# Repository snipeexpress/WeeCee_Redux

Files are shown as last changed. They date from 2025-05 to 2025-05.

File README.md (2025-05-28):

<!-- markdownlint-disable MD031 -->

# WeeCee Redux

**WeeCee Redux** is a hardware clone of Rasteri’s **WeeCee v0.3**, enhanced with a variety of improvements for modern usability, better component choices, and more robust design.

## Key Improvements

1. **HIDman Integration**  
   
   Replaced the legacy PS/2 port with [HIDman](https://github.com/Rasteri/HIDman), enabling support for modern USB HID devices via USB-to-PS/2 translation.

2. **Improved Audio Circuitry**  
   
   Refined the CS4237B circuitry for enhanced signal filtering and improved ground plane separation for cleaner audio performance.

3. **USB-C Power + On/Off Controller**  
   
   Replaced the micro-USB power input with USB-C. Integrated a **MAX16054** on/off controller for reliable power switching.

4. **On-Board PC Speaker**  
   
   Added a miniature PC speaker directly on the board. Can be disabled via jumper if not needed.

5. **Cost-Optimized Connectors**  
   
   Swapped out the MicroSD and audio output connectors for more affordable variants — the same ones used on Eivind Bøhler’s [TinyLlama](https://github.com/eivindbohler/TinyLlama).

6. **Enhanced Front Panel**  
   
   - Added a power button header for direct connection  
   - Added a reset button  
   - Added a power LED to indicate system status

7. **SD Card Activity Indicator**  
   
   Included circuitry and a front-panel LED to show real-time SD card activity.

8. **RTC Battery Support**  
   
   Added support for a **CR1220** coin cell battery to maintain Real-Time Clock settings.

## Enclosure Notes

This revision still fits the original enclosure used in Rasteri’s WeeCee v0.3. However, due to the added ports and indicators, **updated front and rear panels are required** for proper alignment.

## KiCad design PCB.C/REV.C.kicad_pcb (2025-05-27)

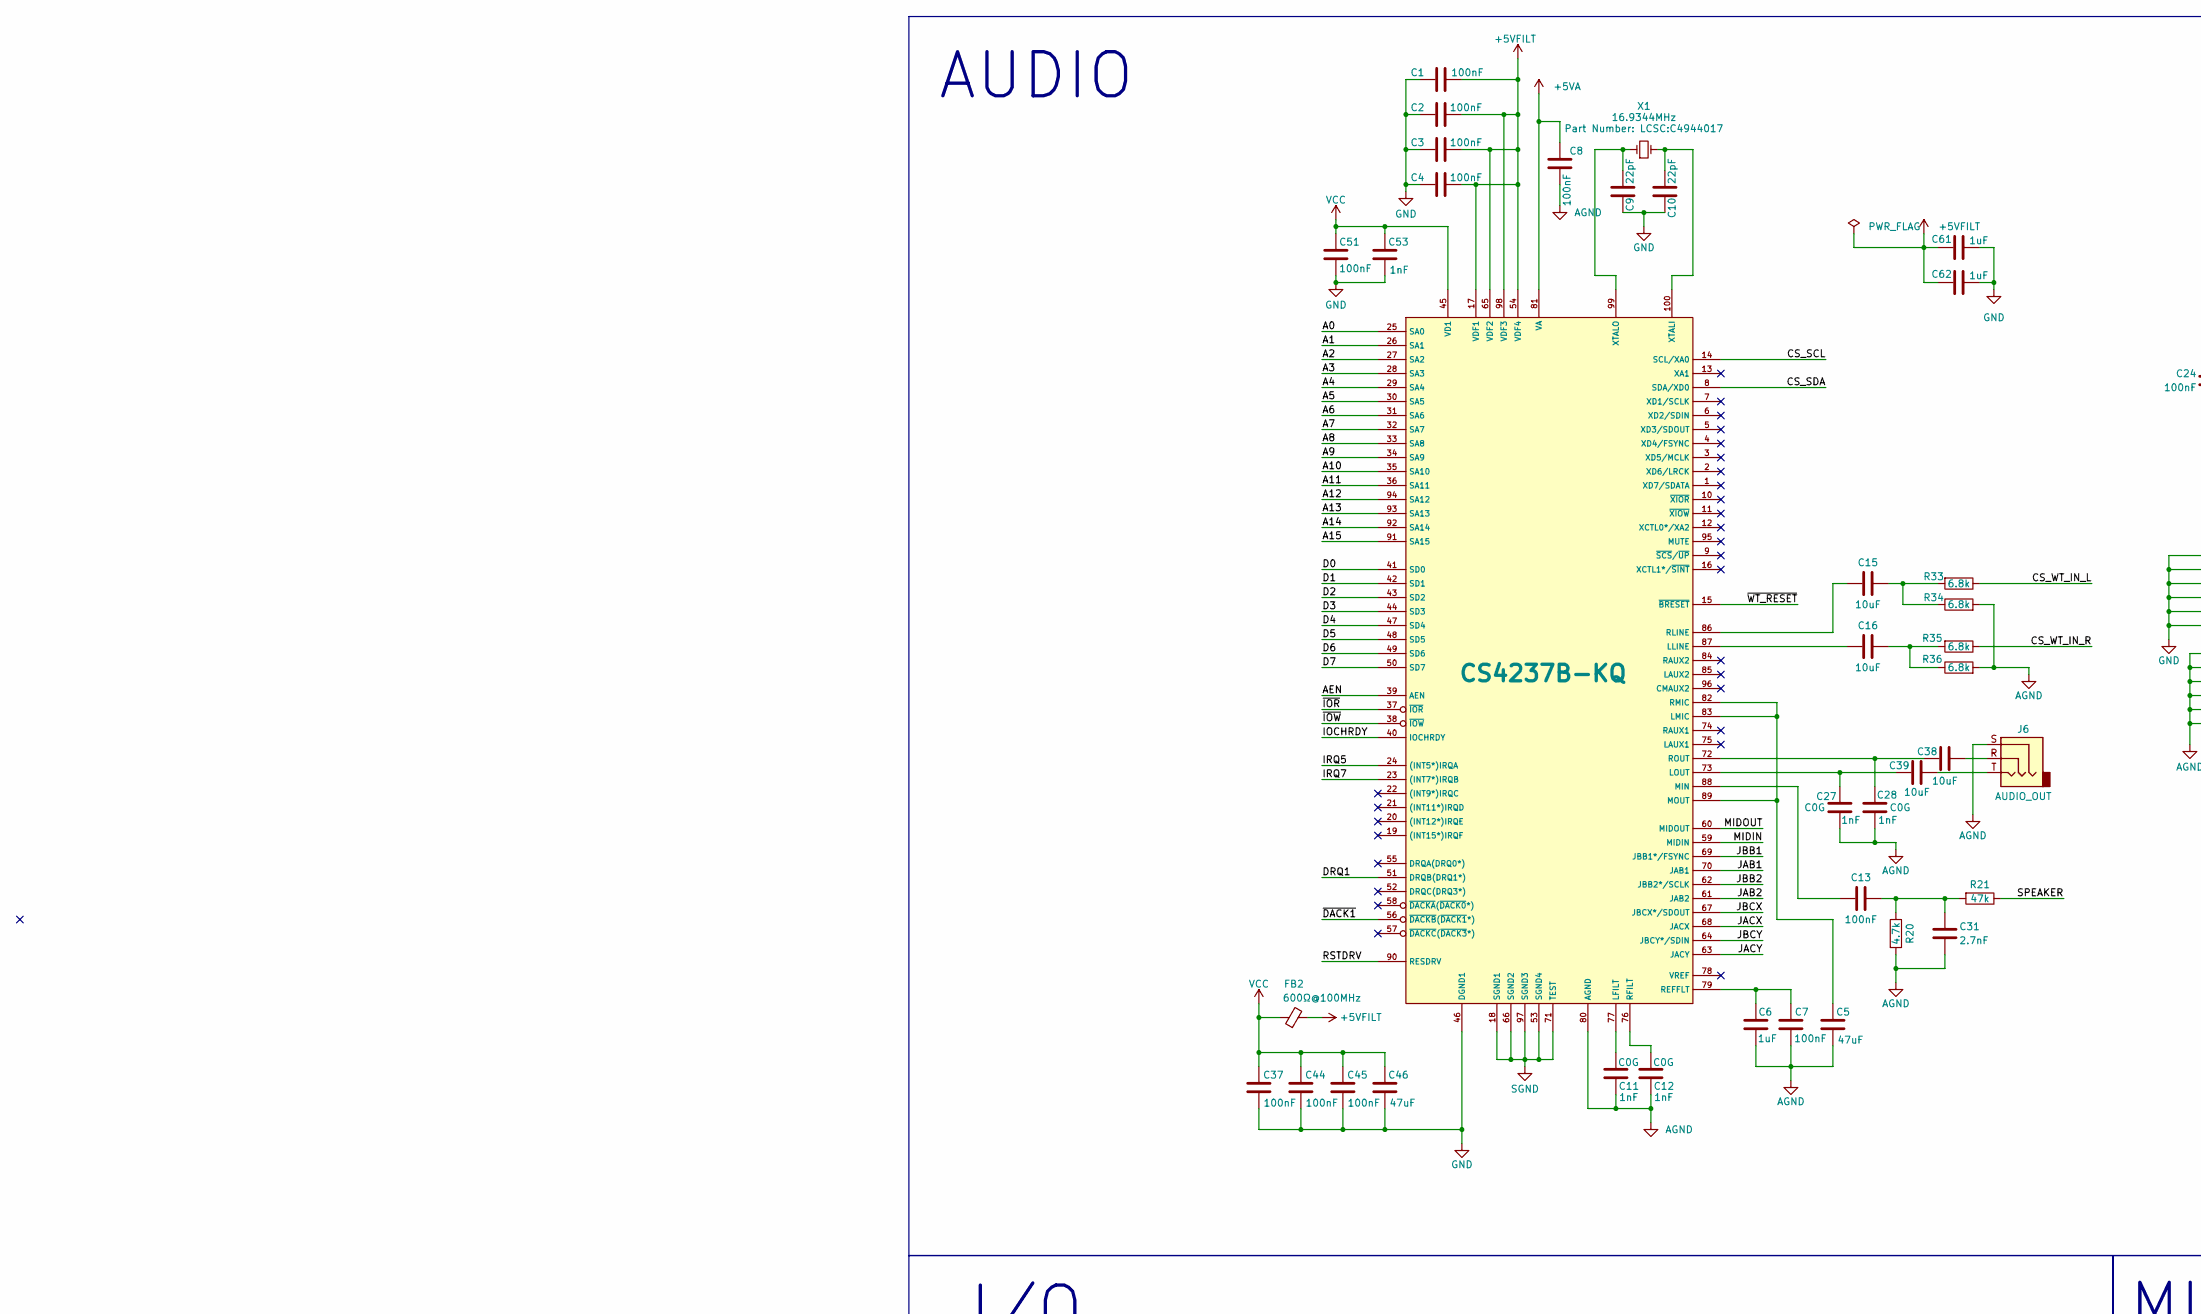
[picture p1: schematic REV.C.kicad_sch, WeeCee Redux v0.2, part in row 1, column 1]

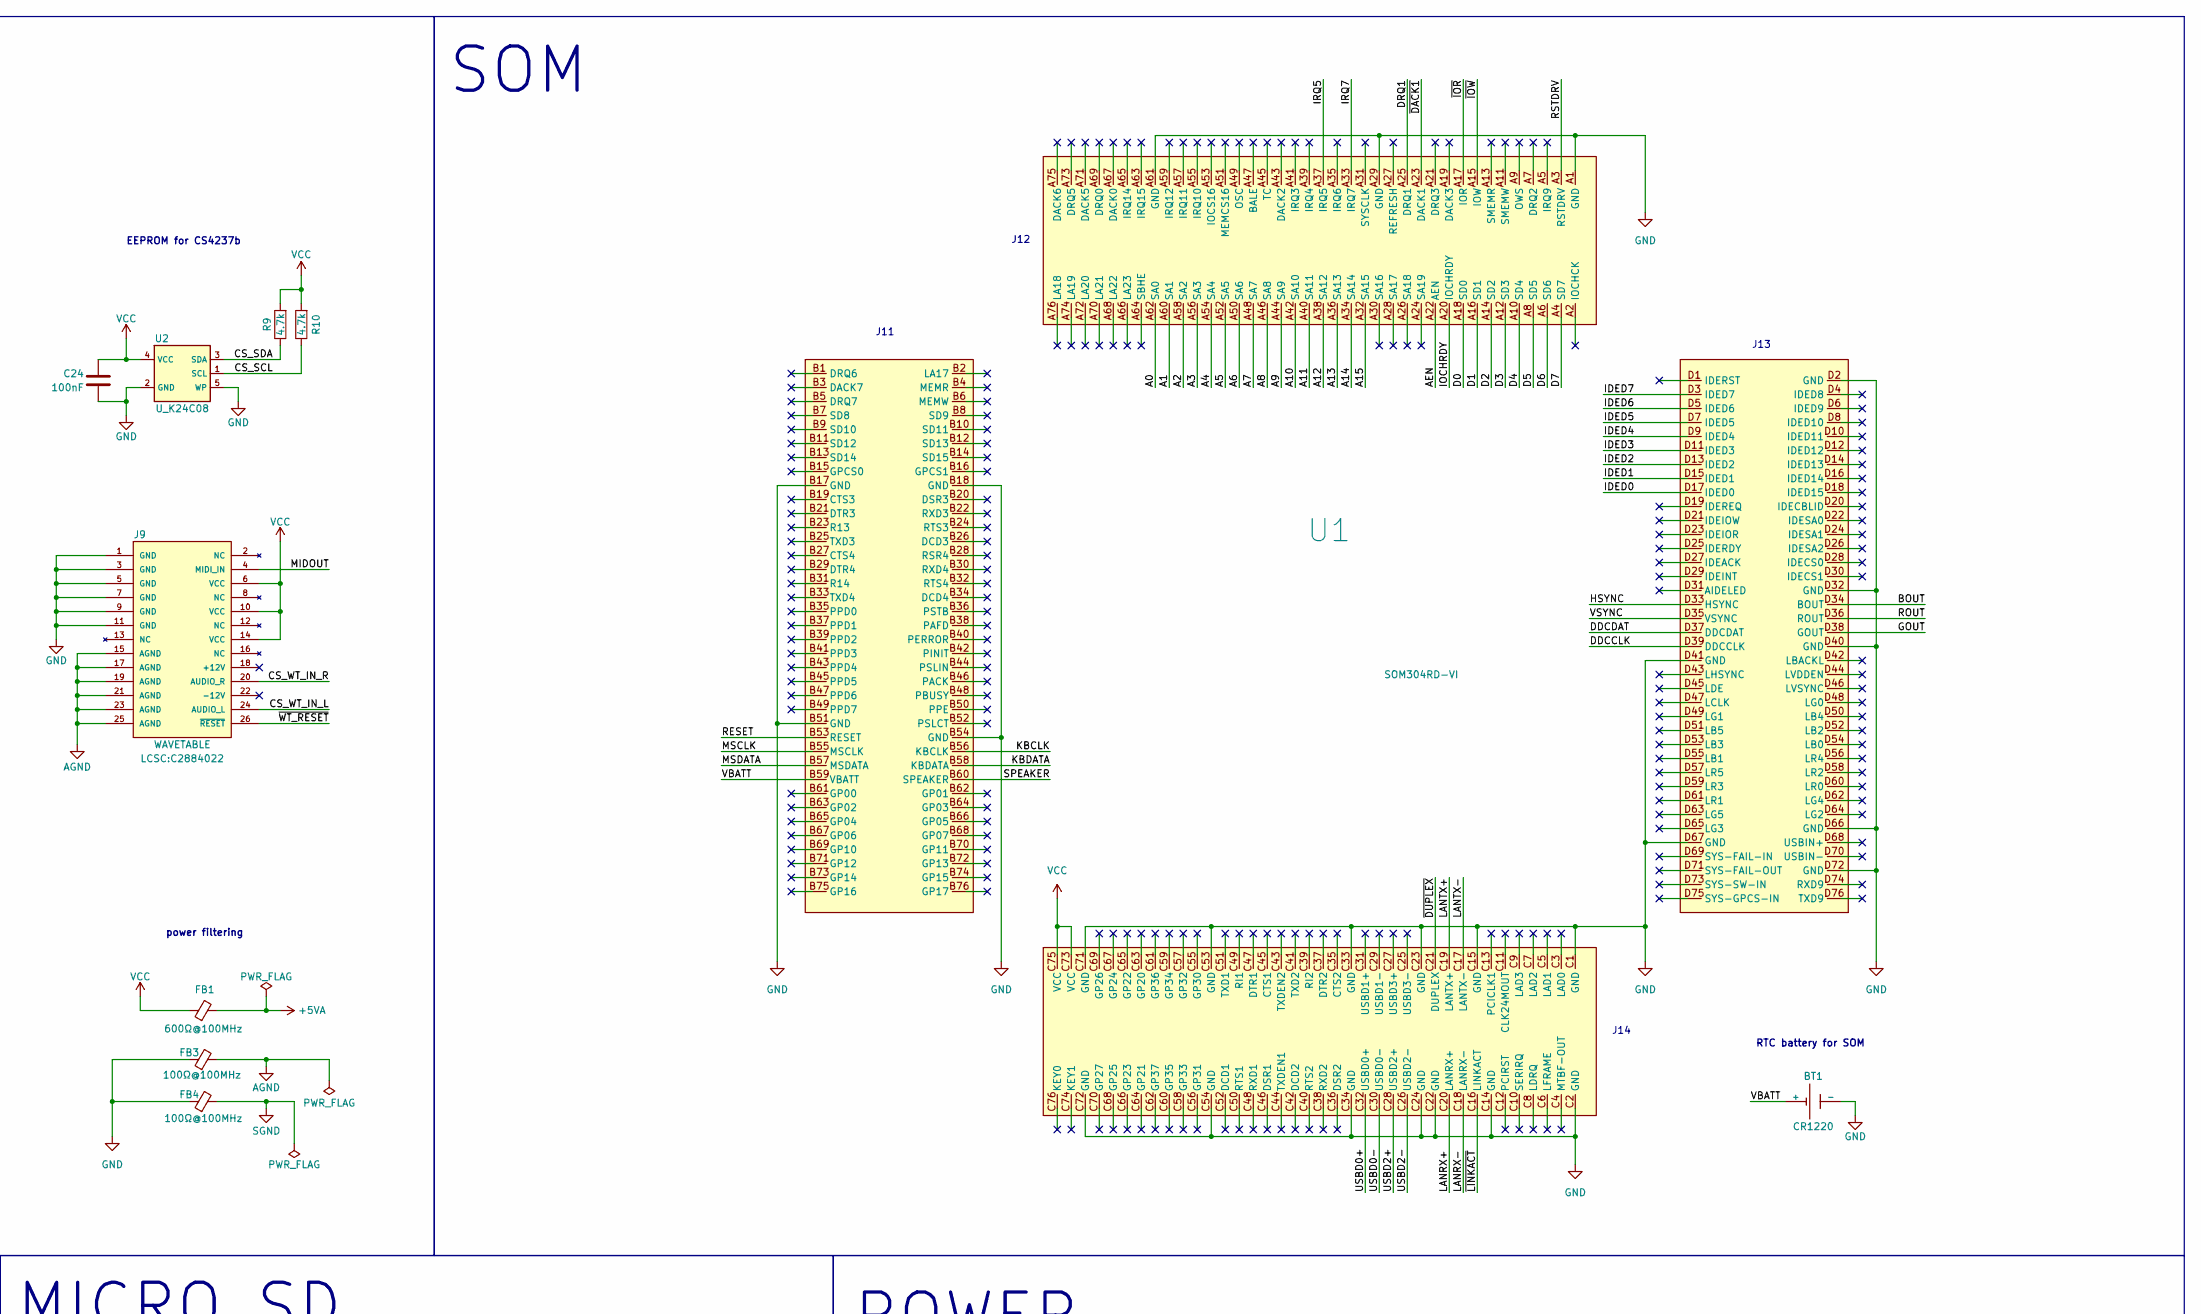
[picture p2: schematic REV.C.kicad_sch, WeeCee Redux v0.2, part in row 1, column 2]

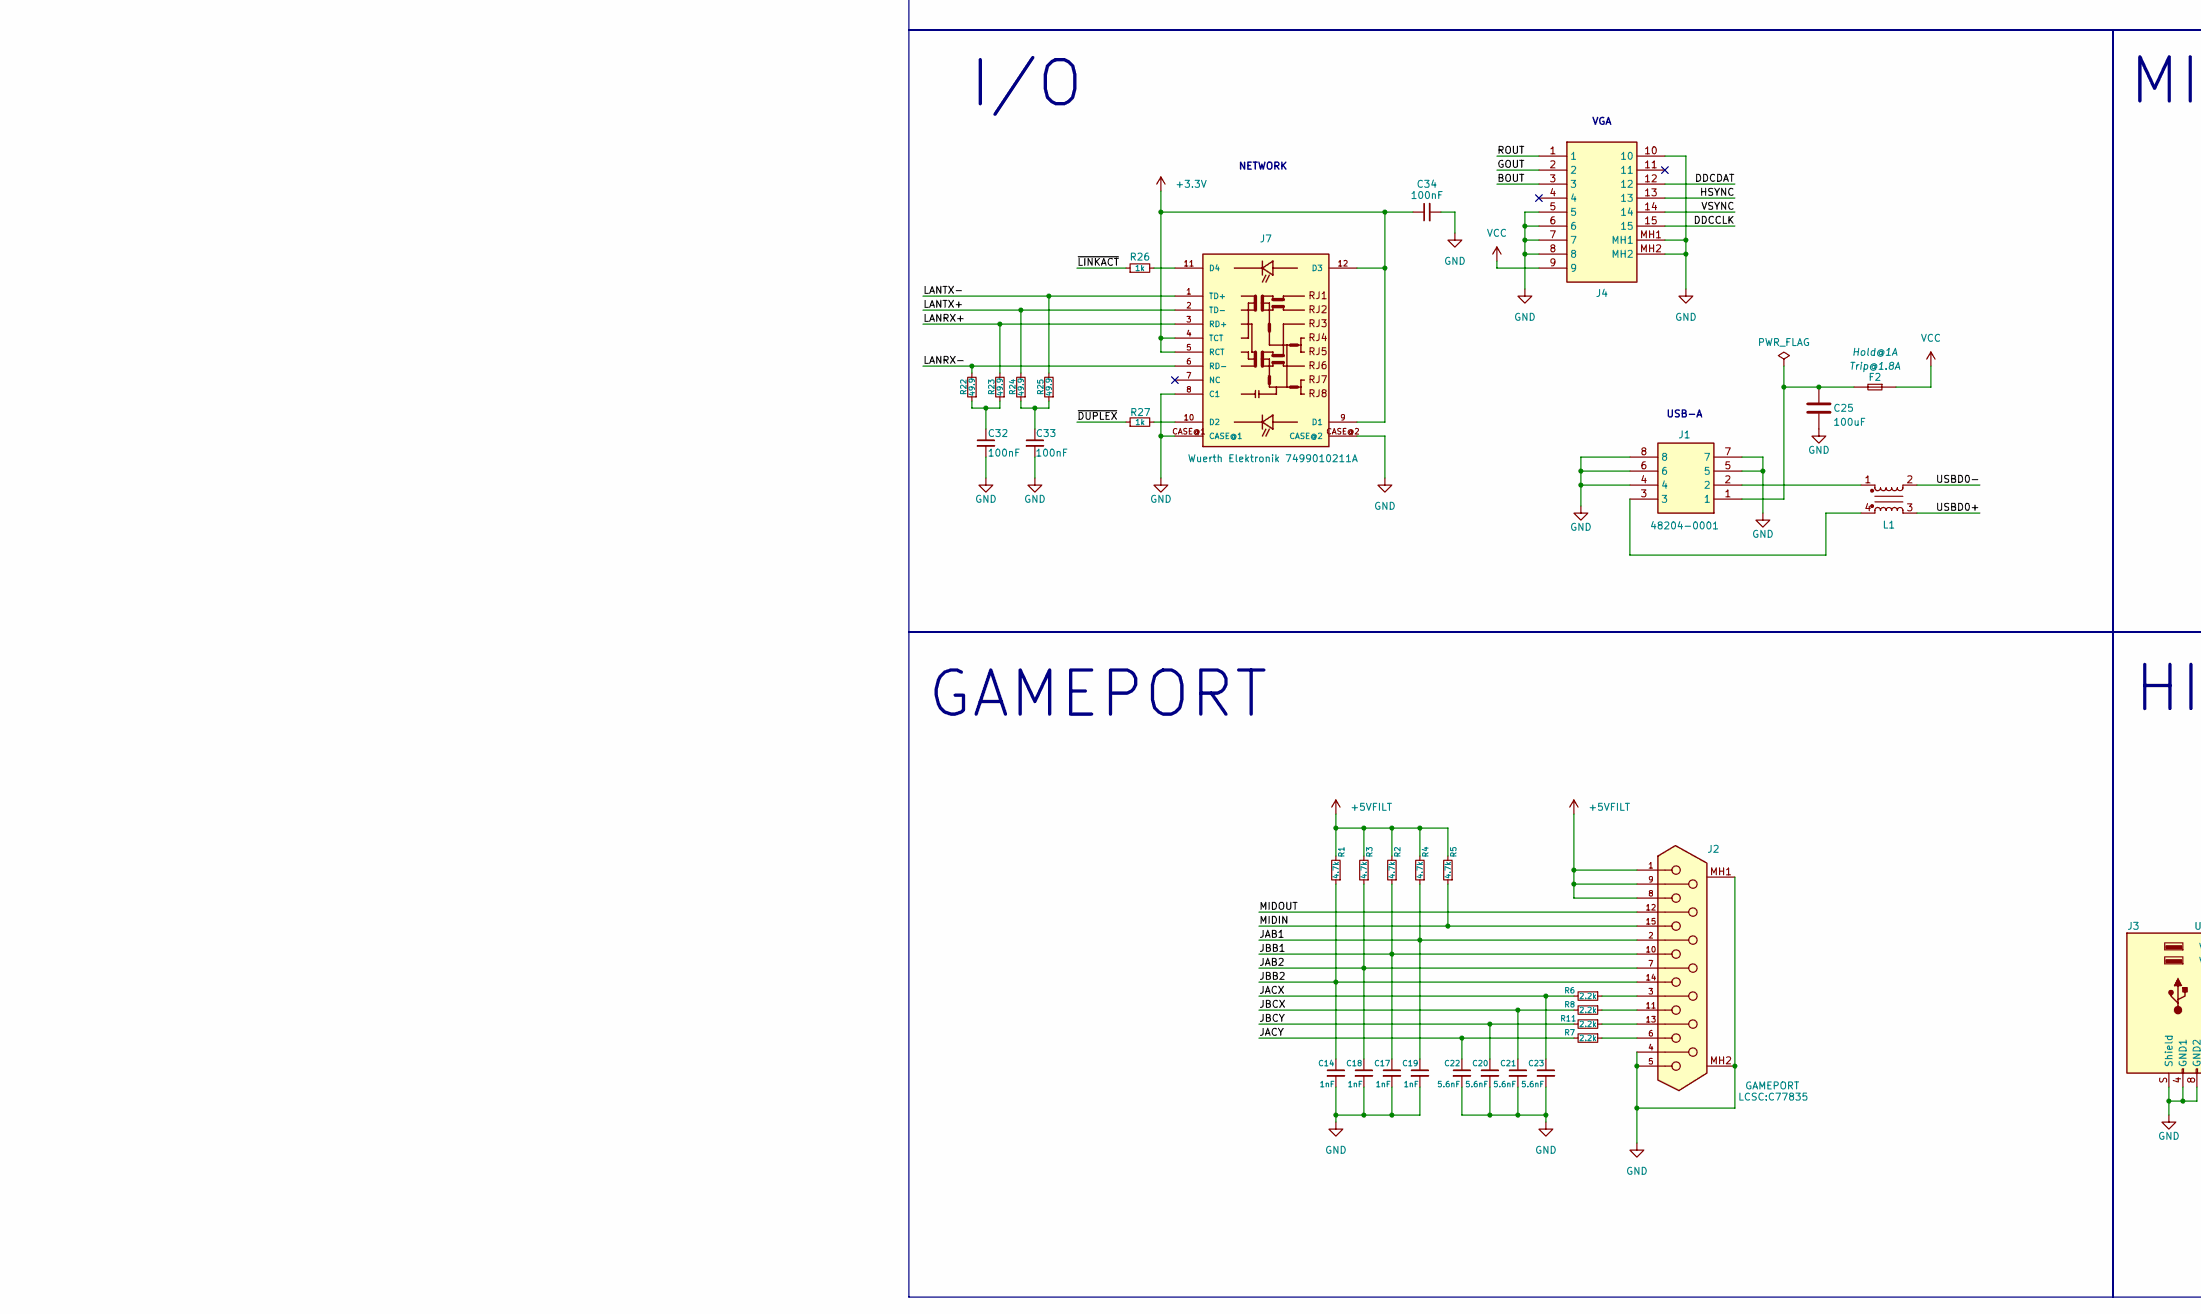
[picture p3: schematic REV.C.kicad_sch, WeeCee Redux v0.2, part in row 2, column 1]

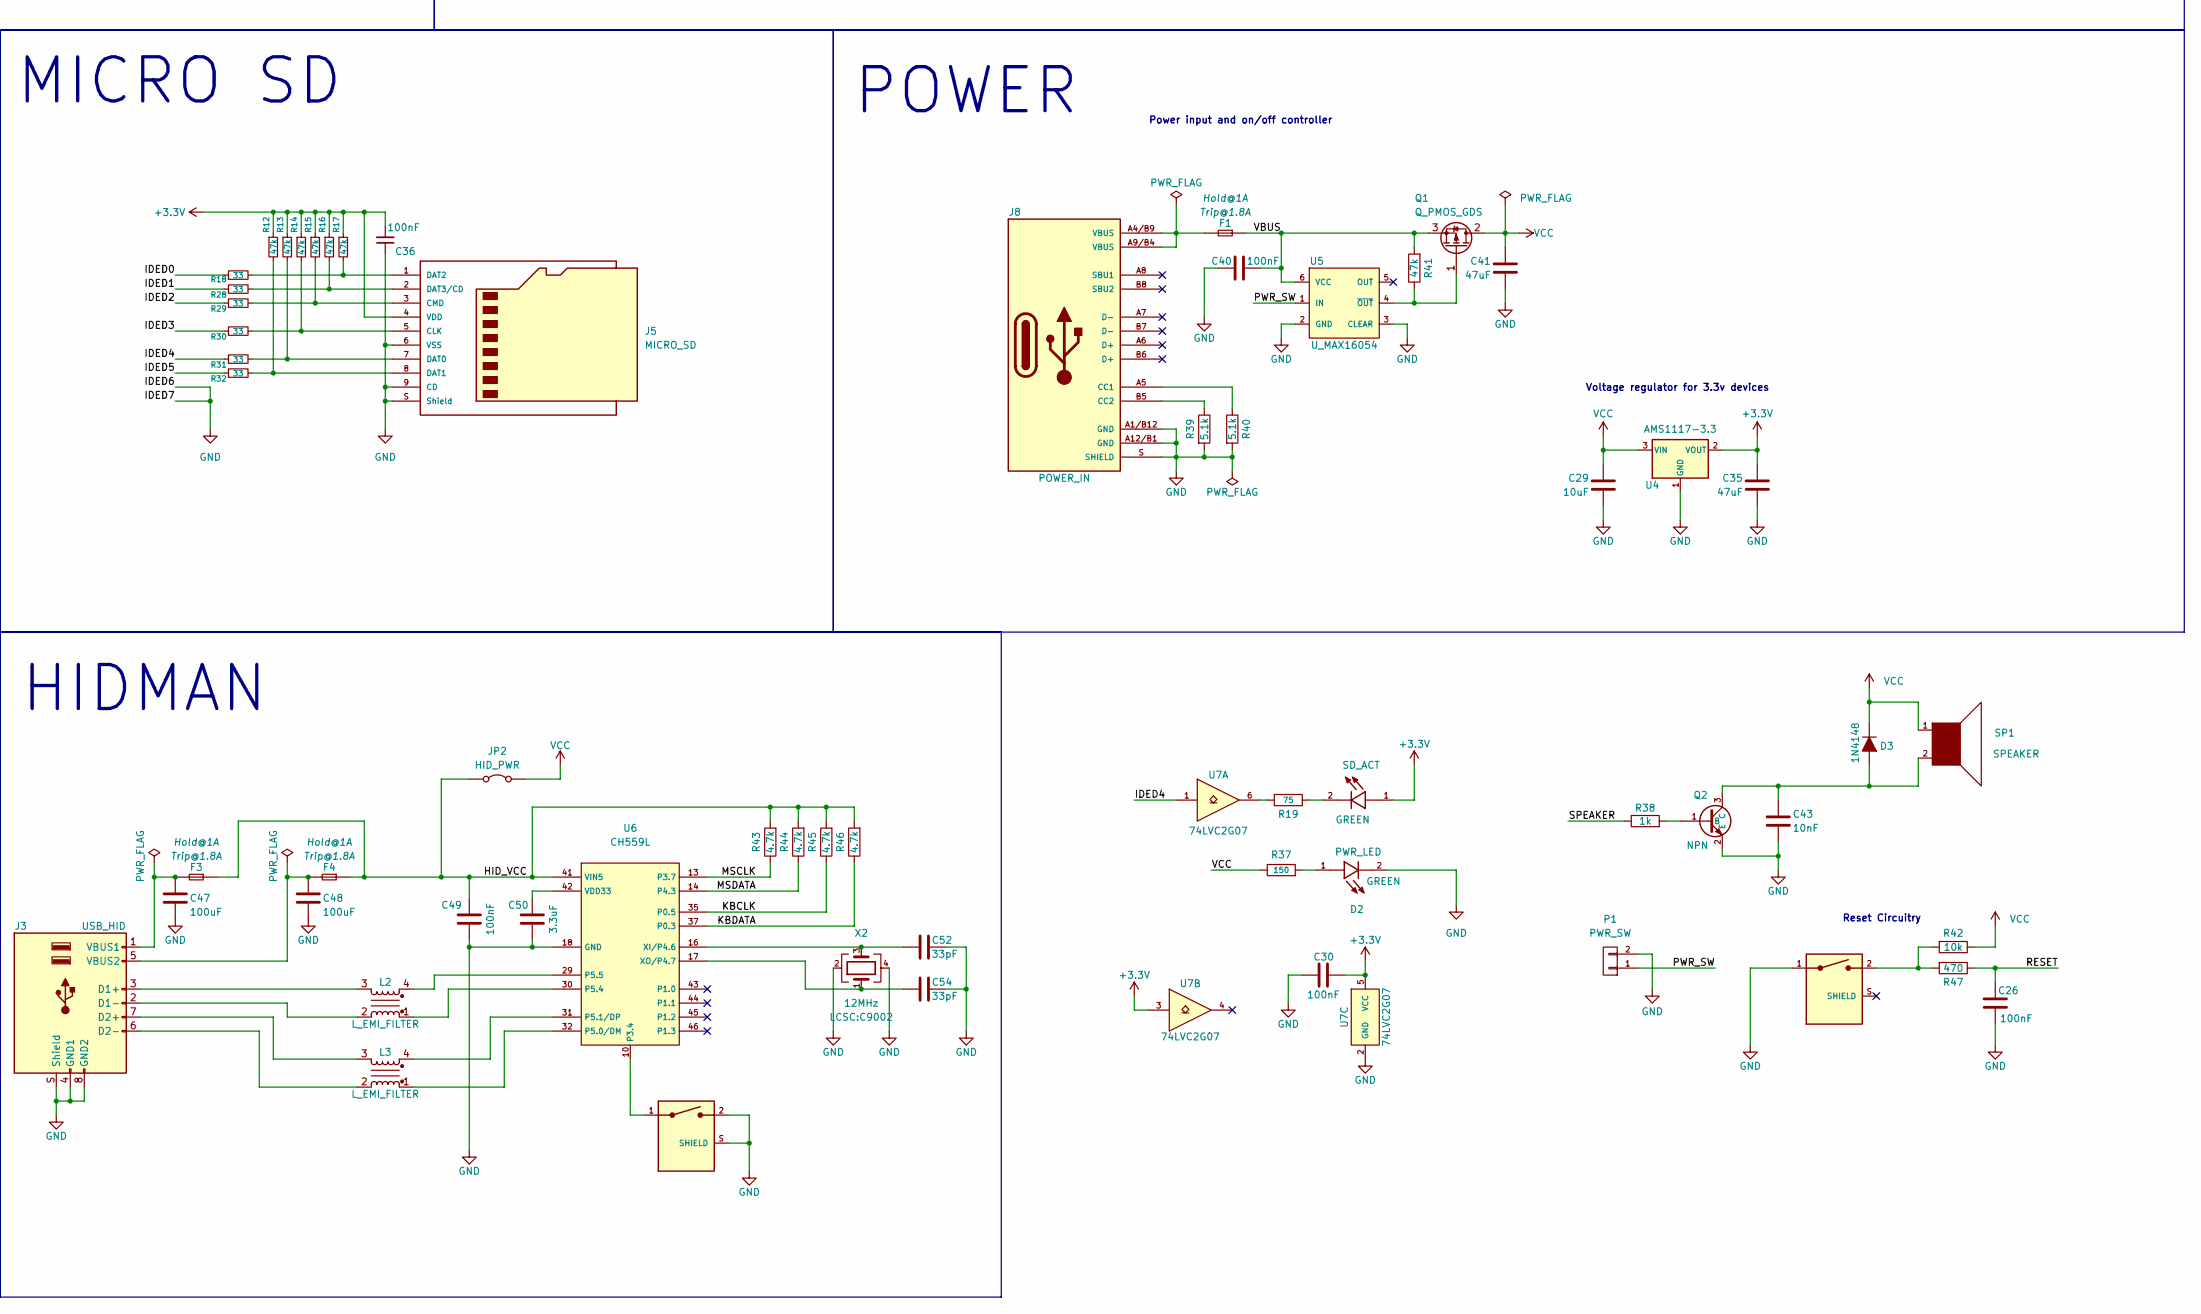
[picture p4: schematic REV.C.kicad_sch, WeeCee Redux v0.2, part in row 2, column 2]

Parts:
BT1: CR1220; BATT-1220-03; Part Number LCSC:C964818
C1, C2, C3, C4, C7, C8, C13, C24, C26, C30, C32, C33, C34, C36, C37, C40, C44, C45, C49, C51: 100nF; C_0603_1608Metric; Part Number DIGIKEY:C0603C104K3RACTU
C5, C35, C41, C46: 47uF; C_1206_3216Metric; Part Number DIGIKEY:C1206C476M8PACTU
C6, C61, C62: 1uF; C_1206_3216Metric; Part Number DIGIKEY:C1206C105K3RACTU
C9, C10: 22pF; C_0603_1608Metric; Part Number DIGIKEY:C0603C220J8GACTU
C11, C12, C27, C28: 1nF; C_0603_1608Metric; Part Number DIGIKEY:GRM1885C1H102JA01D
C14, C17, C18, C19: 1nF; C_0603_1608Metric; Part Number DIGIKEY:C0603C102K3RACTU
C15, C16: 10uF; C_0603_1608Metric; Part Number DIGIKEY:C0603C106M9PACTU
C20, C21, C22, C23: 5.6nF; C_0603_1608Metric; Part Number DIGIKEY:C0603C562K3RACTU
C25, C47, C48: 100uF; C_1206_3216Metric; Part Number DIGIKEY:GRM31CR61A107MEA8K
C29: 10uF; C_1206_3216Metric; Part Number DIGIKEY:C1206C106K4PACTU
C31: 2.7nF; C_0603_1608Metric; Part Number DIGIKEY:C0603C272K5RACTU
C38, C39: 10uF; C_1206_3216Metric; Part Number DIGIKEY: C1206C106K4PACTU
C43: 10nF; C_0603_1608Metric; Part Number DIGIKEY:C0603C103K5RACTU
C50: 3.3uF; C_0603_1608Metric; Part Number DIGIKEY:C0603C335M9PACTU
C52, C54: 33pF; C_0603_1608Metric; Part Number LCSC:C1663
C53: 1nF; C_1206_3216Metric; Part Number DIGIKEY:C0603C102K5RACTU
D1: SD_ACT; LED_LTST-S220KSKT; Part Number DIGIKEY:LTST-S220KGKT
D2: PWR_LED; LED_LTST-S220KSKT; Part Number DIGIKEY:LTST-S220KGKT
D3: 1N4148; D_SOD-323F; Part Number DIGIKEY:1N4148WS-7-F
F1, F2, F3, F4: F; Fuse_0603_1608Metric_no_outline; Part Number DIGIKEY:0603L100SLYR
FB1, FB2: 600Ω@100MHz; R_0805_2012Metric; Part Number DIGIKEY:MPZ2012S601ATD25
FB3, FB4: 100Ω@100MHz; R_0805_2012Metric; Part Number DIGIKEY:MPZ2012S101AT000
J1: 48204-0001; USB-A_1P_VERTICAL; Part Number DIGIKEY:0482040001
J2: GAMEPORT; 57478454; Part Number LCSC:C77835
J3: USB_HID; USB-A_2P_STACKED; Part Number DIGIKEY:C12049
J4: VGA_IN; 634015263032; Part Number DIGIKEY:634-015-263-032
J5: MICRO_SD; MicroSD_TF01A_overhang; Part Number LCSC:C91145
J6: AUDIO_OUT; J_AUDIO35_C95463; Part Number LCSC:C95463
J7: Wuerth Elektronik 7499010211A; NIC_single_port_TH; Part Number DIGIKEY:7499010211A
J8: POWER_IN; USB-C_31-M-12; Part Number LCSC:C165948
J9: WAVETABLE; J_CONN_02X13; Part Number LCSC:C2884022
JP2: HID_PWR; SolderJumper-2_P1.3mm_Open_RoundedPad1.0x1.5mm
L1, L2, L3: L_EMI_FILTER; L_EMI_FILTER_MCM2012B900GBE; Part Number DIGIKEY:MCM2012B900GBEDG
P1: PWR_SW; PinHeader_1x02_P2.00mm_Horizontal; Part Number ALIEXPRESS
Q1: Q_PMOS_GDS; Q_PFET_ENH_SOT-23-3; Part Number DIGIKEY:DMP3099L-7
Q2: NPN; Q_PFET_ENH_SOT-23-3; Part Number LCSC:C2146
R1, R2, R3, R4, R5, R9, R10, R20, R43, R44, R45, R46: 4.7k; R_0603_1608Metric; Part Number DIGIKEY:RC0603FR-074K7L
R6, R7, R8, R11: 2.2k; R_0603_1608Metric; Part Number DIGIKEY:RC0603FR-072K2L
R12, R13, R14, R15, R16, R17, R21, R41: 47k; R_0603_1608Metric; Part Number DIGIKEY:RC0603FR-0747KL
R18, R28, R29, R30, R31, R32: 33; R_0603_1608Metric; Part Number DIGIKEY:RC0603JR-0733RL
R19: 75; R_0603_1608Metric; Part Number DIGIKEY:RC0603JR-0775RL
R22, R23, R24, R25: 49.9; R_0603_1608Metric; Part Number DIGIKEY:RC0603FR-0749R9L
R26, R27, R38: 1k; R_0603_1608Metric; Part Number DIGIKEY:RC0603FR-071KL
R33, R34, R35, R36: 6.8k; R_0603_1608Metric; Part Number DIGIKEY:RC0603JR-076K8L
R37: 150; R_0603_1608Metric; Part Number DIGIKEY:RC0603FR-07150RL
R39, R40: 5.1k; R_0603_1608Metric; Part Number DIGIKEY:RC0603FR-075K1L
R42: 10k; R_0603_1608Metric; Part Number DIGIKEY:RC0603FR-0710KL
R47: 470; R_0603_1608Metric; Part Number DIGIKEY:RC0603JR-07470RL
SP1: SPEAKER; SP; Part Number DIGIKEY:SP3243EEA-L/TR
SW2: RESET; SW_C2859426; Part Number LCSC:C2859426
SW3: HID_PRG; SW_C2859426; Part Number LCSC:C2859426
U1: SOM304RD-VI; Part Number ICOP
U2: U_K24C08; U_SOT-23-5; Part Number DIGIKEY:24LC08BT-I/OT
U3: CS4237B-KQ; U_TQFP-100_14x14mm_P0.5mm_HandSoldering; Part Number UTSOURCE
U4: AMS1117-3.3; U_SOT-223-3; Part Number DIGIKEY:AMS1117-3.3
U5: U_MAX16054; U_TSOT-23-6; Part Number DIGIKEY:MAX16054AZT+T
U6: CH559L; U_QFP-48-0.5mm; Part Number LCSC:C150548
U7: 74LVC2G07; U_SOT-363_SC-70-6; Part Number DIGIKEY:SN74LVC2G07DCKR
X1: 16.9344MHz; X_Crystal_SMD_HC49S-MINI; Part Number LCSC:C4944017
X2: 12MHz; X_SMD3225; Part Number LCSC:C9002

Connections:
+3.3V: C30.1, C34.1, C35.1, C36.2, D1.1, J5.4 (VDD), J7.4 (TCT), J7.5 (RCT), J7.9 (D1), J7.12 (D3), R12.1, R13.1, R14.1, R15.1, R16.1, R17.1, U4.2 (VOUT), U7.3, U7.5 (VCC)
+5VA: C8.2, FB1.2, U3.81 (VA)
+5VFILT: C1.1, C2.1, C3.1, C4.1, C61.2, C62.2, FB2.2, J2.1, J2.8, J2.9, R1.2, R2.2, R3.2, R4.2, R5.2, U3.17 (VDF1), U3.54 (VDF4), U3.65 (VDF2), U3.98 (VDF3)
/A0: U1.A62 (SA0), U3.25 (SA0)
/A1: U1.A60 (SA1), U3.26 (SA1)
/A2: U1.A58 (SA2), U3.27 (SA2)
/A3: U1.A56 (SA3), U3.28 (SA3)
/A4: U1.A54 (SA4), U3.29 (SA4)
/A5: U1.A52 (SA5), U3.30 (SA5)
/A6: U1.A50 (SA6), U3.31 (SA6)
/A7: U1.A48 (SA7), U3.32 (SA7)
/A8: U1.A46 (SA8), U3.33 (SA8)
/A9: U1.A44 (SA9), U3.34 (SA9)
/A10: U1.A42 (SA10), U3.35 (SA10)
/A11: U1.A40 (SA11), U3.36 (SA11)
/A12: U1.A38 (SA12), U3.94 (SA12)
/A13: U1.A36 (SA13), U3.93 (SA13)
/A14: U1.A34 (SA14), U3.92 (SA14)
/A15: U1.A32 (SA15), U3.91 (SA15)
/AEN: U1.A22 (AEN), U3.39 (AEN)
/BOUT: J4.3, U1.D34 (BOUT)
/CS_SCL: R10.1, U2.1 (SCL), U3.14 (SCL/XA0)
/CS_SDA: R9.1, U2.3 (SDA), U3.8 (SDA/XD0)
/CS_WT_IN_L: J9.24 (AUDIO_L), R33.1
/CS_WT_IN_R: J9.20 (AUDIO_R), R35.1
/D0: U1.A18 (SD0), U3.41 (SD0)
/D1: U1.A16 (SD1), U3.42 (SD1)
/D2: U1.A14 (SD2), U3.43 (SD2)
/D3: U1.A12 (SD3), U3.44 (SD3)
/D4: U1.A10 (SD4), U3.47 (SD4)
/D5: U1.A8 (SD5), U3.48 (SD5)
/D6: U1.A6 (SD6), U3.49 (SD6)
/D7: U1.A4 (SD7), U3.50 (SD7)
/DDCCLK: J4.15, U1.D39 (DDCCLK)
/DDCDAT: J4.12, U1.D37 (DDCDAT)
/DRQ1: U1.A25 (DRQ1), U3.51 (DRQB(DRQ1*))
/GOUT: J4.2, U1.D38 (GOUT)
/HID_VCC: C49.2, F3.1, F4.1, JP2.1 (A), R43.2, R44.2, R45.2, R46.2, U6.41 (VIN5)
/HSYNC: J4.13, U1.D33 (HSYNC)
/IDED0: R18.1, U1.D17 (IDED0)
/IDED1: R28.1, U1.D15 (IDED1)
/IDED2: R29.1, U1.D13 (IDED2)
/IDED3: R30.1, U1.D11 (IDED3)
/IDED4: R31.1, U1.D9 (IDED4), U7.1
/IDED5: R32.1, U1.D7 (IDED5)
/IOCHRDY: U1.A20 (IOCHRDY), U3.40 (IOCHRDY)
/IRQ5: U1.A37 (IRQ5), U3.24 ((INT5*)IRQA)
/IRQ7: U1.A33 (IRQ7), U3.23 ((INT7*)IRQB)
/JAB1: C19.1, J2.2, R4.1, U3.70 (JAB1)
/JAB2: C18.1, J2.7, R3.1, U3.61 (JAB2)
/JACX: C23.1, R6.2, U3.68 (JACX)
/JACY: C22.1, R7.2, U3.63 (JACY)
/JBB1: C17.1, J2.10, R2.1, U3.69 (JBB1*/FSYNC)
/JBB2: C14.1, J2.14, R1.1, U3.62 (JBB2*/SCLK)
/JBCX: C21.1, R8.2, U3.67 (JBCX*/SDOUT)
/JBCY: C20.1, R11.2, U3.64 (JBCY*/SDIN)
/KBCLK: R45.1, U1.B56 (KBCLK), U6.35 (P0.5)
/KBDATA: R46.1, U1.B58 (KBDATA), U6.37 (P0.3)
/LANRX+: J7.3 (RD+), R23.2, U1.C20 (LANRX+)
/LANRX-: J7.6 (RD-), R22.2, U1.C18 (LANRX-)
/LANTX+: J7.2 (TD-), R24.2, U1.C19 (LANTX+)
/LANTX-: J7.1 (TD+), R25.2, U1.C17 (LANTX-)
/MIDIN: J2.15, R5.1, U3.59 (MIDIN)
/MIDOUT: J2.12, J9.4 (MIDI_IN), U3.60 (MIDOUT)
/MSCLK: R43.1, U1.B55 (MSCLK), U6.13 (P3.7)
/MSDATA: R44.1, U1.B57 (MSDATA), U6.14 (P4.3)
/PWR_SW: P1.1, U5.1 (IN)
/RESET: C26.2, R47.1, U1.B53 (RESET)
/ROUT: J4.1, U1.D36 (ROUT)
/RSTDRV: U1.A3 (RSTDRV), U3.90 (RESDRV)
/SPEAKER: R21.1, R38.1, U1.B60 (SPEAKER)
/USBD0+: L1.3, U1.C32 (USBD0+)
/USBD0-: L1.2, U1.C30 (USBD0-)
/USBD2+: U1.C28 (USBD2+)
/USBD2-: U1.C26 (USBD2-)
/VBATT: BT1.1 (+), U1.B59 (VBATT)
/VBUS: C40.2, F1.1, Q1.3 (S), R41.2, U5.6 (VCC)
/VSYNC: J4.14, U1.D35 (VSYNC)
/~DACK1: U1.A23 (DACK1), U3.56 (~DACKB(~DACK1*))
/~DUPLEX: R27.1, U1.C21 (DUPLEX)
/~IOR: U1.A17 (IOR), U3.37 (~IOR)
/~IOW: U1.A15 (IOW), U3.38 (~IOW)
/~LINKACT: R26.1, U1.C16 (LINKACT)
/~WT_RESET: J9.26 (~RESET), U3.15 (~BRESET)
AGND: C5.2, C6.2, C7.2, C8.1, C11.1, C12.1, C27.2, C28.2, C31.2, FB3.2, J6.S, J9.15 (AGND), J9.17 (AGND), J9.19 (AGND), J9.21 (AGND), J9.23 (AGND), J9.25 (AGND), R20.2, R34.2, R36.2, U3.80 (AGND)
GND: BT1.2 (-), C1.2, C2.2, C3.2, C4.2, C9.1, C10.1, C14.2, C17.2, C18.2, C19.2, C20.2, C21.2, C22.2, C23.2, C24.2, C25.2, C26.1, C29.2, C30.2, C32.2, C33.2, C34.2, C35.2, C36.1, C37.1, C40.1, C41.2, C43.2, C44.1, C45.1, C46.2, C47.2, C48.2, C49.1, C50.1, C51.2, C52.2, C53.2, C54.2, C61.1, C62.1, D2.2, FB3.1, FB4.1, J1.4, J1.5, J1.6, J1.7, J1.8, J2.4, J2.5, J2.MH1, J2.MH2, J3.4 (GND1), J3.8 (GND2), J3.S (Shield), J4.5, J4.6, J4.7, J4.8, J4.10, J4.MH1, J4.MH2, J5.6 (VSS), J5.9 (CD), J5.S (Shield), J7.8 (C1), J7.CASE@1, J7.CASE@2, J8.A1/B12 (GND), J8.A12/B1 (GND), J8.S (SHIELD), J9.1 (GND), J9.3 (GND), J9.5 (GND), J9.7 (GND), J9.9 (GND), J9.11 (GND), P1.2, Q2.2 (E), R39.2, R40.2, SW2.1, SW3.2, SW3.S (SHIELD), U1.A1 (GND), U1.A29 (GND), U1.A61 (GND), U1.B17 (GND), U1.B18 (GND), U1.B51 (GND), U1.B54 (GND), U1.C1 (GND), U1.C2 (GND), U1.C14 (GND), U1.C15 (GND), U1.C22 (GND), U1.C23 (GND), U1.C24 (GND), U1.C33 (GND), U1.C34 (GND), U1.C53 (GND), U1.C54 (GND), U1.C71 (GND), U1.C72 (GND), U1.D2 (GND), U1.D3 (IDED7), U1.D5 (IDED6), U1.D32 (GND), U1.D40 (GND), U1.D41 (GND), U1.D66 (GND), U1.D67 (GND), U1.D72 (GND), U2.2 (GND), U2.5 (WP), U3.46 (DGND1), U4.1 (GND), U5.2 (GND), U5.3 (CLEAR), U6.18 (GND), U7.2 (GND), X2.2, X2.4
unnamed: C13.2, C31.1, R20.1, R21.2
unnamed: C15.2, R33.2, R34.1
unnamed: C16.2, R35.2, R36.1
unnamed: C25.1, F2.2, J1.1
unnamed: C32.1, R22.1, R23.1
unnamed: C33.1, R24.1, R25.1
unnamed: C38.2, J6.R
unnamed: C39.2, J6.T
unnamed: D1.2, R19.1
unnamed: D2.1, R37.2
unnamed: C43.1, D3.2 (A), Q2.3 (C), SP1.2
unnamed: F1.2, J8.A4/B9 (VBUS), J8.A9/B4 (VBUS)
unnamed: J1.2, L1.1
unnamed: J1.3, L1.4
unnamed: J2.3, R6.1
unnamed: J2.6, R7.1
unnamed: J2.11, R8.1
unnamed: J2.13, R11.1
unnamed: J3.3 (D1+), L2.3
unnamed: J3.2 (D1-), L2.2
unnamed: J3.7 (D2+), L3.3
unnamed: J3.6 (D2-), L3.2
unnamed: C47.1, F3.2, J3.1 (VBUS1)
unnamed: C48.1, F4.2, J3.5 (VBUS2)
unnamed: J5.5 (CLK), R14.2, R30.2
unnamed: J5.3 (CMD), R15.2, R29.2
unnamed: J5.7 (DAT0), R13.2, R31.2
unnamed: J5.8 (DAT1), R12.2, R32.2
unnamed: J5.1 (DAT2), R17.2, R18.2
unnamed: J5.2 (DAT3/CD), R16.2, R28.2
unnamed: J7.10 (D2), R27.2
unnamed: J7.11 (D4), R26.2
unnamed: J8.A5 (CC1), R40.1
unnamed: J8.B5 (CC2), R39.1
unnamed: Q1.1 (G), R41.1, U5.4 (~OUT)
unnamed: Q2.1 (B), R38.2
unnamed: R19.2, U7.6
unnamed: R42.2, R47.2, SW2.2
unnamed: C11.2, U3.77 (LFILT)
unnamed: C16.1, U3.87 (LLINE)
unnamed: C5.1, U3.82 (RMIC), U3.83 (LMIC), U3.89 (MOUT)
unnamed: C27.1, C39.1, U3.73 (LOUT)
unnamed: C13.1, U3.88 (MIN)
unnamed: C6.1, C7.1, U3.79 (REFFLT)
unnamed: C12.2, U3.76 (RFILT)
unnamed: C15.1, U3.86 (RLINE)
unnamed: C28.1, C38.1, U3.72 (ROUT)
unnamed: C10.2, U3.100 (XTALI), X1.2
unnamed: C9.2, U3.99 (XTALO), X1.1
unnamed: SW3.1, U6.10 (P3.4)
unnamed: L3.1, U6.32 (P5.0/DM)
unnamed: L3.4, U6.31 (P5.1/DP)
unnamed: L2.1, U6.30 (P5.4)
unnamed: L2.4, U6.29 (P5.5)
unnamed: C50.2, U6.42 (VDD33)
unnamed: C52.1, U6.16 (XI/P4.6), X2.3
unnamed: C54.1, U6.17 (XO/P4.7), X2.1
SGND: FB4.2, U3.18 (SGND1), U3.53 (SGND4), U3.66 (SGND2), U3.71 (TEST), U3.97 (SGND3)
VCC: C24.1, C29.1, C37.2, C41.1, C44.2, C45.2, C46.1, C51.1, C53.1, D3.1 (K), F2.1, FB1.1, FB2.1, J4.9, J9.6 (VCC), J9.10 (VCC), J9.14 (VCC), JP2.2 (B), Q1.2 (D), R9.2, R10.2, R37.1, R42.1, SP1.1, U1.C73 (VCC), U1.C75 (VCC), U2.4 (VCC), U3.45 (VD1), U4.3 (VIN)

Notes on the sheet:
POWER
J13
MICRO SD
GAMEPORT
AUDIO
RTC battery for SOM
J11
J14
VGA
J12
Voltage regulator for 3.3v devices
Power input and on/off controller
Reset Circuitry
HIDMAN
power filtering
NETWORK
I/O
EEPROM for CS4237b
SOM
USB-A

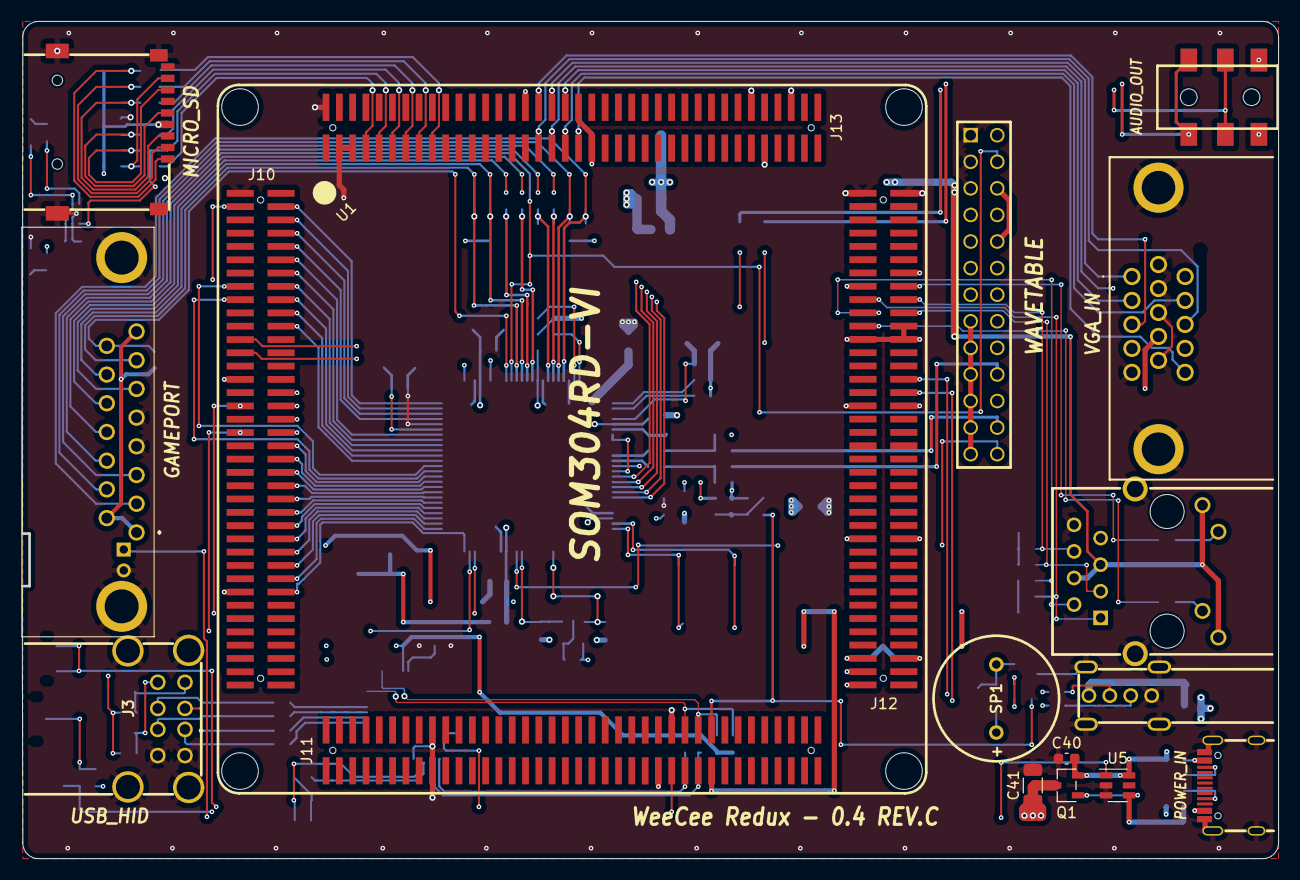
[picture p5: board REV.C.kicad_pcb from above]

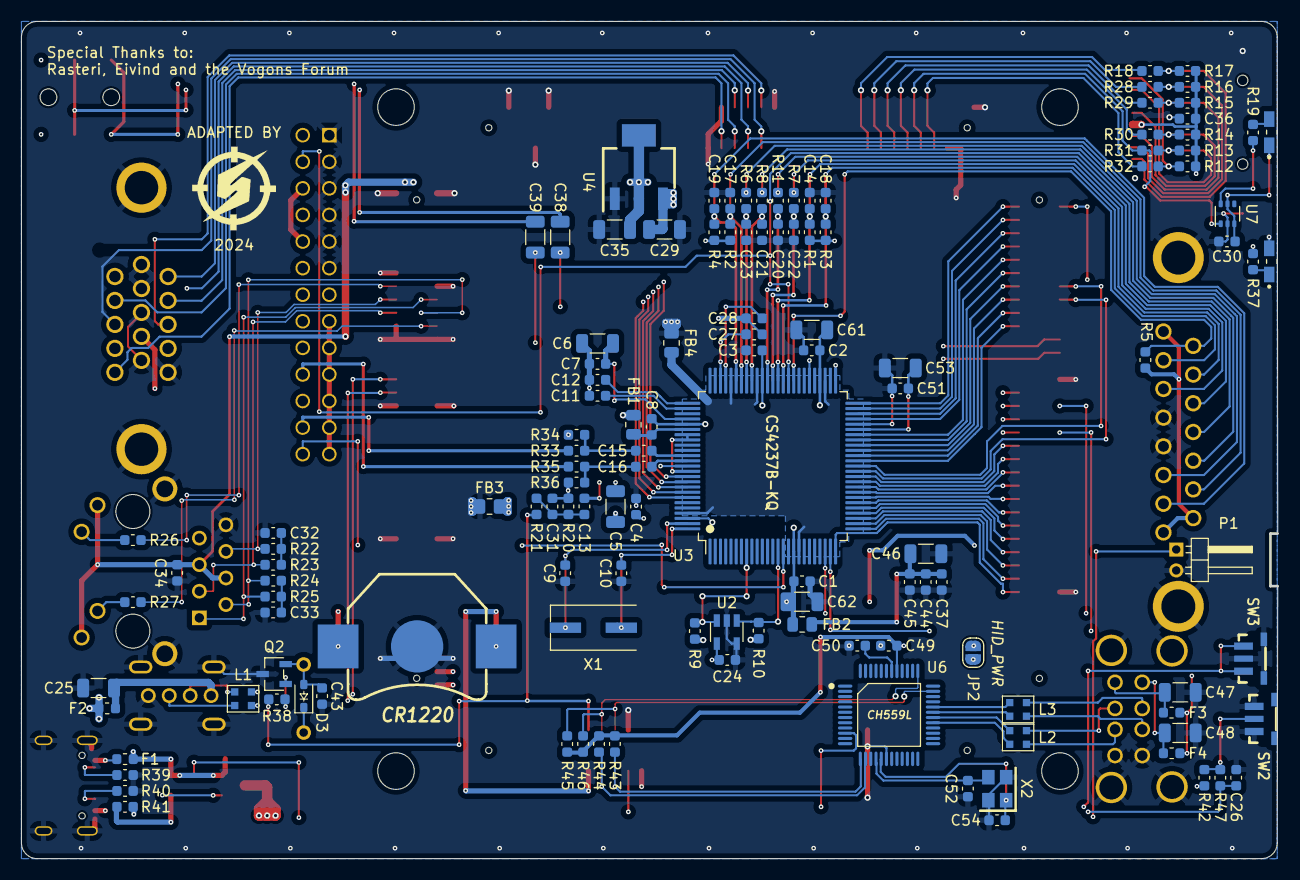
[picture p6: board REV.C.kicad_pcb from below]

Board: 4 copper layers, 120.0 x 80.0 mm, 143 parts (128 on the bottom side), 143 nets.

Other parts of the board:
2024: 2024; snipe_96x96px

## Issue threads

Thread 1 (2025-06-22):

[Feature Request] Placement map, please?

vanfanel, 2025-06-22:
Hello there, @snipeexpress

I am very interested in this because I already have the needed Vortex86 DX SOM running on another board: I was about to order some WeeCee boards at PCBWay or similar when I was told by rasteri about this improved WeeCee!

Sadly, I lack the ability or materiasl to solder the components manually, so it would be very convenient for me to order some WeeCee Redux boards at PCBWay, but I would need to provide the placement map so I can get pre-assembled boards.

So, could you please add a placement map to the project so I can order it pre-assembled?

Thanks!!

Closed 2025-07-11.
